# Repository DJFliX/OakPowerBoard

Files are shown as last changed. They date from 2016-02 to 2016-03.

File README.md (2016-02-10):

# OakPowerBoard
A Power Consumption board using the TCRT5000 to count pulses. The board is intended as a shield for DigiStump's Oak board. Check it out [here](http://digistump.com/oak/)!

##How does it look?
Great question, I've made screenshots of the board I sent to OSH-Park:
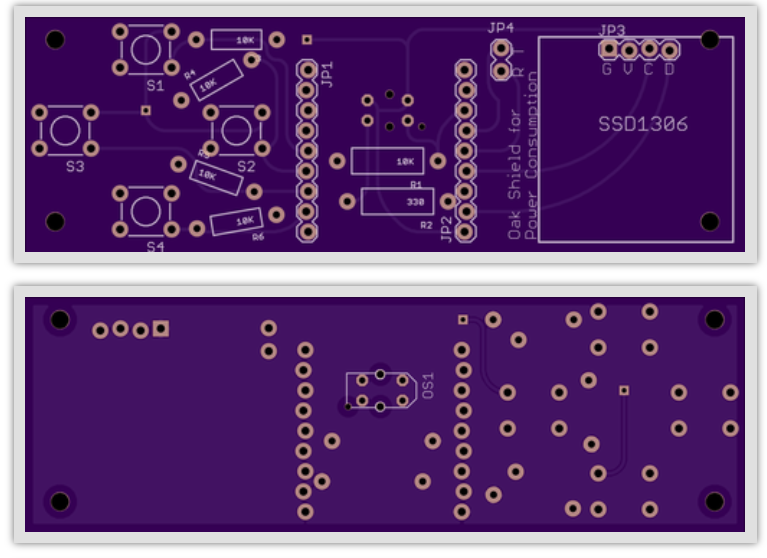
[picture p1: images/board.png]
Image of board


##Is the code finished?
I've made some progress on the code, but unfortunately to test the real sensor I'll have to wait until the board from oshpark arrive. For now, I'm simulating the pulse meter with a button. Below you can find a list of features that are already implemented as well as features that will be implemented in the near future.

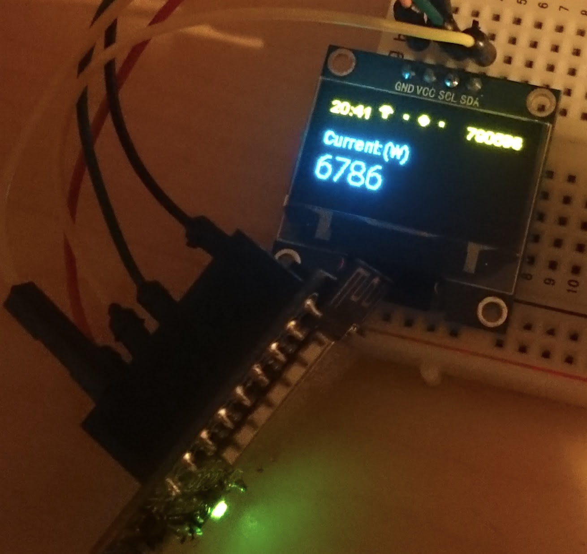
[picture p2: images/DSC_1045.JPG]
Image of firmware running on the Oak


Done:
- [X] Show (& calc) total consumption
- [X] Use interrupts to get button input + pulses
- [X] Use button input to switch between frames
- [X] Persistent storage of KWh counter

Future wishes:
- [ ] Add NTP time to sketch
- [ ] Implement timezone offset, apply to current time
- [ ] Keep track of total consumption for the day (and display this)
- [ ] Create some kind of menu for settings
- [ ] Set counter starting position
- [ ] Send consumption to some kind of server?
- [ ] Calibration of pulse detection?
- [ ] Multi-SSID
- [ ] Store measurements while there is no Wi-Fi connection
- [ ] Work stand-alone (without Wi-Fi connection) without switching to Config mode
- [ ] Reduce Flash memory wear by writing periodically instead of on every KWh increment

##Resources used
* [SparkFun Eagle Libraries](https://github.com/sparkfun/SparkFun-Eagle-Libraries) by [SparkFun](https://github.com/sparkfun)
* [TCRT5000 Eagle Library](https://github.com/mohamedpsx/Eagle-Libraries) by [mohamedpsx](https://github.com/mohamedpsx)

* [esp8266-oled-ssd1306](https://github.com/squix78/esp8266-oled-ssd1306) by [squix78](https://github.com/squix78))
* [EEPROMWriteAnything](http://playground.arduino.cc/Code/EEPROMWriteAnything) by the Arduino Community

* [AirSensor Energy Monitor tutorial](http://www.airsensor.co.uk/component/zoo/item/energy-monitor.html)
* [nongnu.org dtostrf](http://www.nongnu.org/avr-libc/user-manual/group__avr__stdlib.html#ga060c998e77fb5fc0d3168b3ce8771d42)
* [SSD1306 Tools Font Converter](http://oleddisplay.squix.ch)

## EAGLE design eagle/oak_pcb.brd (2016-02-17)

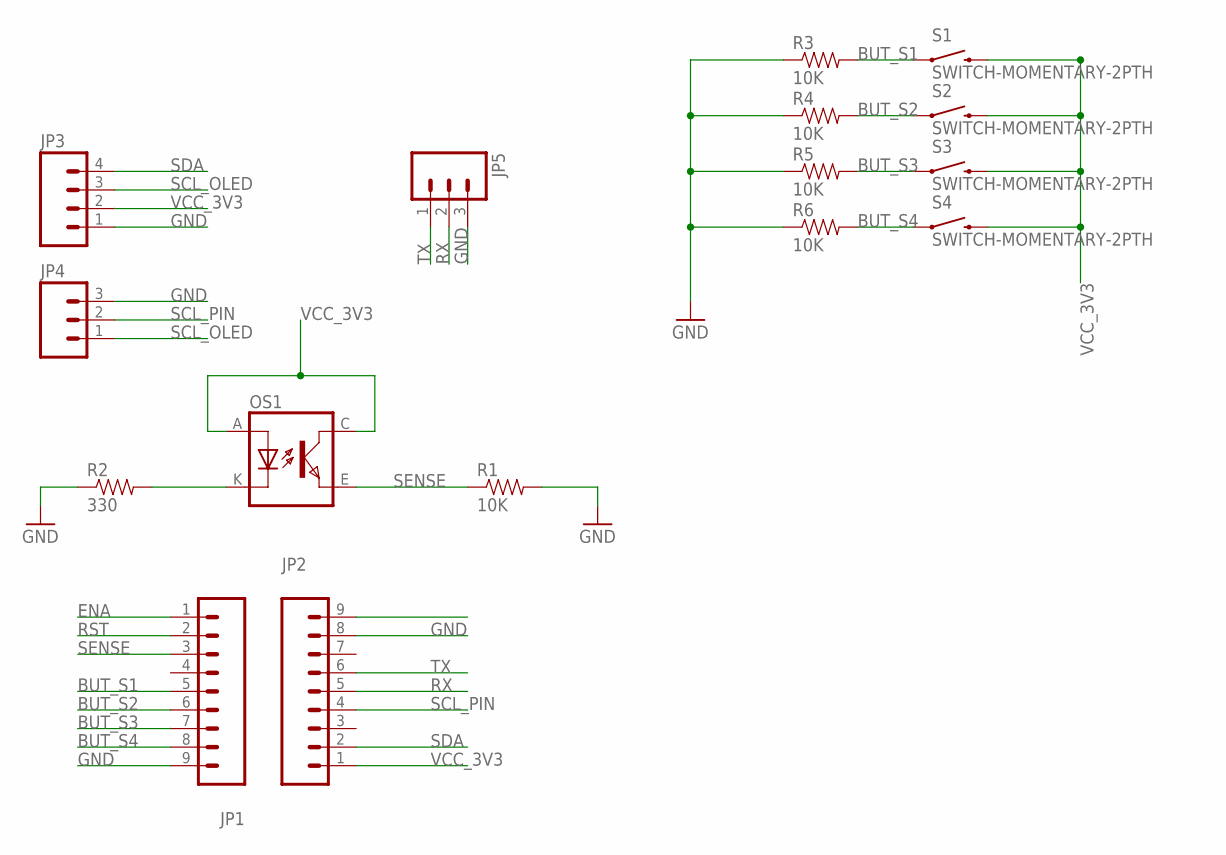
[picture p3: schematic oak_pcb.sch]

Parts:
JP1, JP2: M09LOCK; 1X09_LOCK
JP3: M04LOCK; 1X04_LOCK
JP4, JP5: M03LOCK; 1X03_LOCK
OS1: TCRT5000
R1, R3, R4, R5, R6: 10K; AXIAL-0.4
R2: 330; AXIAL-0.4
S1, S2, S3, S4: SWITCH-MOMENTARY-2PTH; TACTILE-PTH

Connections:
BUT_S1: JP1.5, R3.P$2 (2), S1.1
BUT_S2: JP1.6, R4.P$2 (2), S2.1
BUT_S3: JP1.7, R5.P$2 (2), S3.1
BUT_S4: JP1.8, R6.P$2 (2), S4.1
ENA: JP1.1
GND: JP1.9, JP2.8, JP3.1, JP4.3, JP5.3, R1.P$2 (2), R2.P$1 (1), R3.P$1 (1), R4.P$1 (1), R5.P$1 (1), R6.P$1 (1)
unnamed: OS1.K (CATHODE), R2.P$2 (2)
RST: JP1.2
RX: JP2.5, JP5.2
SCL_OLED: JP3.3, JP4.1
SCL_PIN: JP2.4, JP4.2
SDA: JP2.2, JP3.4
SENSE: JP1.3, OS1.E (EMITTER), R1.P$1 (1)
TX: JP2.6, JP5.1
VCC_3V3: JP2.1, JP3.2, OS1.A (ANODE), OS1.C (COLLECTOR), S1.3 (2), S2.3 (2), S3.3 (2), S4.3 (2)

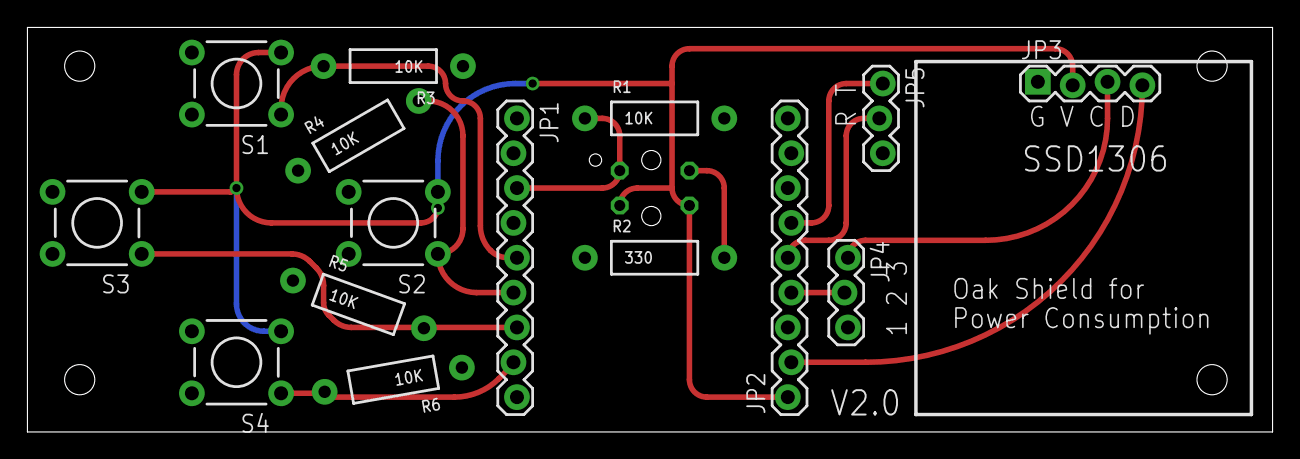
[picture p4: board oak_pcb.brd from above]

Board: 2 copper layers, 90.8 x 29.5 mm, 16 parts (1 on the bottom side), 13 nets.

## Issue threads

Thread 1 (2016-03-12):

Arduino sketch doesn't handle PUT and POST with payload

DJFliX, 2016-03-12:
Find out how to parse payload on incoming requests. Specifically, I'd like to parse the KWH value so we can set in from the browser sketch

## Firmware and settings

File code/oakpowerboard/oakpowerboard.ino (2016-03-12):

#include <Wire.h>
#include <EEPROM.h>

//https://github.com/squix78/esp8266-oled-ssd1306
#include "SSD1306.h"
#include "SSD1306Ui.h"

//Resources included with the sketch
#include "roboto_10.h"
#include "roboto_12.h"
#include "roboto_thin_20.h"
#include "images.h"

#include "eepromanything.h"

#define PULSES_PER_KWH 375
#define WH_PER_PULSE (1000.0F / PULSES_PER_KWH)

#define BTN_1 9
#define BTN_2 8
#define BTN_3 7
#define BTN_4 6
#define PULSE_PIN A0
#define DEBUG_LED 1

//#define DEBUG

#define EEPROM_READ_ADDR 0

struct config_t
{
  int state;
  double consumption_total;
  int pulse_count_current_kwh;
} storage;

double particle_total_kwh = 0;
char consumption_total_str[10] = "00000.00";

double particle_consumption_current = 0;
char consumption_current_str[6] = "Wait";

long time_since_last_pulse = millis();

// Initialize the oled display for address 0x3c
SSD1306   display(0x3c, 0, 2);
SSD1306Ui ui     ( &display );

struct measurement_values {
  int counter = 0;
  int value = 0;
  int hi = 0;
  int lo = 1024;
} analogVal;

struct measurement_strings {
  char current[5] = "0000";
  char hi[5] = "0000";
  char lo[5] = "0000";
} valStrings;

enum app_state {
  HOME,
  CALIBRATE
};

app_state current_state = HOME;

/* Drawing Resources */
bool draw_totalcount_frame(SSD1306 *display, SSD1306UiState* state, int x, int y);
bool draw_currentconsumption_frame(SSD1306 *display, SSD1306UiState* state, int x, int y);
bool draw_menu_frame(SSD1306 *display, SSD1306UiState* state, int x, int y);
bool msOverlay(SSD1306 *display, SSD1306UiState* state);

float get_consumption_from_time_since_last_pulse(long timeSinceLastPulse);

// this array keeps function pointers to all frames
// frames are the single views that slide from right to left
bool (*frames[])(SSD1306 *display, SSD1306UiState* state, int x, int y) = { 
  draw_totalcount_frame, 
  draw_currentconsumption_frame
};

// this array keeps function pointers to all frames
// frames are the single views that slide from right to left
bool (*others[])(SSD1306 *display, SSD1306UiState* state, int x, int y) = { 
  draw_menu_frame,
  draw_calibration_frame
};

bool (*overlays[])(SSD1306 *display, SSD1306UiState* state) = { 
  msOverlay 
};

bool isConnected = false;
bool b1_pressed = false;
bool b2_pressed = false;
bool b3_pressed = false;
bool b4_pressed = false;
bool pulse_triggered = false;

void toggle_b1() { b1_pressed = true; }
void toggle_b2() { b2_pressed = true; }
void toggle_b3() { b3_pressed = true; }
void toggle_b4() { b4_pressed = true; }
void trigger_pulse() { pulse_triggered = true; }

void setup() {
  Particle.variable("total", particle_total_kwh);
  Particle.variable("current", particle_consumption_current);
  EEPROM_readAnything(EEPROM_READ_ADDR, storage);
  if(storage.state != 0xFA) {
    storage.state = 0xFA;
    storage.consumption_total = 56713.0f;
    storage.pulse_count_current_kwh = 370;
    EEPROM_writeAnything(EEPROM_READ_ADDR, storage);
  }
  
  dtostrf(storage.consumption_total, 6, 2, consumption_total_str);
  
  ui.setTargetFPS(30);
  ui.setActiveSymbole(activeSymbole);
  ui.setInactiveSymbole(inactiveSymbole);
  ui.setIndicatorPosition(TOP);
  ui.setIndicatorDirection(LEFT_RIGHT);
  ui.setFrameAnimation(SLIDE_LEFT);
  ui.setTimePerFrame(7000);
  ui.setFrames(frames, 2);
  ui.setOverlays(overlays, 1);
  ui.init();

  display.flipScreenVertically();
  
#ifdef DEBUG
  pinMode(DEBUG_LED, OUTPUT);//Debugging LED
#endif
  attachInterrupt(digitalPinToInterrupt(BTN_1), toggle_b1, FALLING);
  attachInterrupt(digitalPinToInterrupt(BTN_2), toggle_b2, FALLING);
  attachInterrupt(digitalPinToInterrupt(BTN_3), toggle_b3, FALLING);
  attachInterrupt(digitalPinToInterrupt(BTN_4), toggle_b4, FALLING);
}

void loop() {
  int remainingTimeBudget = ui.update();
  long deadline = millis() + remainingTimeBudget;
  
  if (remainingTimeBudget > 0) {
    yield();
    if(b1_pressed == true) {
      switch(current_state) {
        case HOME:
          ui.setFrames(others, 2);
          ui.disableAutoTransition();
          current_state = CALIBRATE;
          break;
        case CALIBRATE:
          ui.setFrames(frames, 2);
          ui.enableAutoTransition();
          current_state = HOME;
          break;
      }
      //handle b1
      b1_pressed = false;
      yield();
    }
    
    if(b2_pressed == true) {
      //handle b2
      ui.nextFrame();
      b2_pressed = false;
      yield();
    }
    
    if(b3_pressed == true) {
      //handle b3
      ui.previousFrame();
      b3_pressed = false;
      yield();
    }
    
    if(b4_pressed == true) {
      //handle b4
      switch(current_state) {
        case CALIBRATE:
          analogVal.hi = 0;
          dtostrf(analogVal.hi, 4, 0, valStrings.hi);
          analogVal.lo = 1024;
          dtostrf(analogVal.lo, 4, 0, valStrings.lo);
          break;
      }
      b4_pressed = false;
      yield();
    }

    analogVal.counter++;
    if(analogVal.counter == 5) {
      analogVal.value = analogRead(PULSE_PIN);
      if(analogVal.value > analogVal.hi) {
        analogVal.hi = analogVal.value;
        dtostrf(analogVal.hi, 4, 0, valStrings.hi);
      }
      if(analogVal.value < analogVal.lo) {
        analogVal.lo = analogVal.value;
        dtostrf(analogVal.lo, 4, 0, valStrings.lo);
      }
      dtostrf(analogVal.value, 4, 0, valStrings.current);
      analogVal.counter = 0;
    }
    
    /*if(pulse_triggered == true) {
        storage.pulse_count_current_kwh++;
        if(storage.pulse_count_current_kwh == PULSES_PER_KWH) {
          storage.consumption_total++;
          storage.pulse_count_current_kwh = 0;
          EEPROM_writeAnything(EEPROM_READ_ADDR, storage);
        }
        yield();
        particle_consumption_current = get_consumption_from_time_since_last_pulse(time_since_last_pulse);
        particle_total_kwh = storage.consumption_total + ((((float)storage.pulse_count_current_kwh) * WH_PER_PULSE) / 1000.0F);
        dtostrf(particle_total_kwh, 6, 2, consumption_total_str);
        dtostrf(particle_consumption_current, 4, 0, consumption_current_str);
        time_since_last_pulse = millis();
        pulse_triggered = false;
        yield();
    }*/
#ifdef DEBUG
    digitalWrite(DEBUG_LED, millis() < deadline ? HIGH : LOW);
#endif
    yield();
    if(millis() < deadline) delay(deadline - millis());
  }
}

bool draw_totalcount_frame(SSD1306 *display, SSD1306UiState* state, int x, int y) {
  display->setTextAlignment(TEXT_ALIGN_LEFT);
  display->setFont(Roboto_Plain_10);
  display->drawString(0 + x, 20, "Total (kWh):");
  display->setFont(Roboto_Thin_Plain_20);
  display->drawString(0 + x, 32, consumption_total_str);
  return false;
}

bool draw_currentconsumption_frame(SSD1306 *display, SSD1306UiState* state, int x, int y) {
  display->setTextAlignment(TEXT_ALIGN_LEFT);
  display->setFont(Roboto_Plain_10);
  display->drawString(0 + x, 20, "Current: (W)");
  display->setFont(Roboto_Thin_Plain_20);
  display->drawString(0 + x, 34, consumption_current_str);
  return false;
}

bool draw_menu_frame(SSD1306 *display, SSD1306UiState* state, int x, int y) {
  display->setTextAlignment(TEXT_ALIGN_LEFT);
  display->setFont(Roboto_Plain_10);
  display->drawString(0 + x, 20, "MENU: (W)");
  return false;
}

bool draw_calibration_frame(SSD1306 *display, SSD1306UiState* state, int x, int y) {
  display->setTextAlignment(TEXT_ALIGN_LEFT);
  display->setFont(Roboto_Plain_10);
  display->drawString(12 + x, 16, "Current: ");
  display->drawString(12 + x, 28, "High: ");
  display->drawString(12 + x, 40, "Low: ");
  display->drawString(x, 52, "S4: RST S3: BCK S2: Ok");
  display->setTextAlignment(TEXT_ALIGN_RIGHT);
  display->drawString(128 + x, 16, valStrings.current);
  display->drawString(128 + x, 28, valStrings.hi);
  display->drawString(128 + x, 40, valStrings.lo);
  display->drawString(128 + x, 52, analogVal.value > ((analogVal.hi + analogVal.lo) / 2) ? "X" : " ");
  return false;
}

bool msOverlay(SSD1306 *display, SSD1306UiState* state) {
  //display->drawXbm(32, 0, 8, 8, wifiActive);
  display->setTextAlignment(TEXT_ALIGN_LEFT);
  display->setFont(Roboto_Plain_10);
  display->drawString(0, 0, valStrings.current); //This should be the current time
  //display->setTextAlignment(TEXT_ALIGN_RIGHT);
  //display->drawString(128, 0, String(millis()));
  return true;
}

float get_consumption_from_time_since_last_pulse(long timeSinceLastPulse) {
  long time = millis();
  long dsecs = (time - timeSinceLastPulse) / 100;
  if(dsecs < 4) { //4 dsecs = 0.4 sec: the highest supported interval for this sketch.
    time_since_last_pulse = time;
    return 0.0F;
  }
  float result = (WH_PER_PULSE / (dsecs / 36000.0F));
  return result;
}

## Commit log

2016-02-03 Added Board Files
    [oak_pcb.brd, oak_pcb.sch]
2016-02-03 Update readme and add board image from oshpark.
2016-02-04 Moved eagle files and modified Readme.md
    [oak_pcb.brd, oak_pcb.sch]
2016-02-04 Add the display loop
    Added three frames that are displayed. The current frames are: total
    power consumption (KWh), current consumption (W), and consumption today
    (KWh). Of course, data is static.
2016-02-04 Added initial pulse calculation and string conversion
    When a pulse is detected (currently emulated using a button) the
    current power consumption is calculated and displayed on the screen.
    The value for “Current (W)” is now actually based on the float value.
    Total is based on the float value, but is not updated properly. Today
    is not implemented yet, as we don’t have time yet.
2016-02-07 Corrected current consumption calculation formula.
    [oakpowerboard.ino]
2016-02-07 Fixed calculation of total KWH
    [oakpowerboard.ino]
2016-02-07 Delay with the remaining budget after measuring pulse instead
    Also: comment these lines out because apparently a delay is a problem.
    [oakpowerboard.ino]
2016-02-09 Removed the frame that we don't use (consumption today)
2016-02-09 Oops... forgot to commit the changes concerning the not-so-dynamic number of frames and overlays...
2016-02-09 Replace the digitalRead with interrupt-based triggers.
    [oakpowerboard.ino]
2016-02-09 Increase the display time per frame
2016-02-16 Move fonts to root, apparently Arduino 1.6.5 does not like subfolders.
    Strangely enough, it worked on 1.6.7… But that version had other issues.
    [oakpowerboard.ino]
2016-02-16 Added extra yields to lower the WiFi congestion during the loop
    Also fixed an ugly bug that made the loop delay forever.
    [oakpowerboard.ino]
2016-02-17 Board update, fixed some unfortunate mistakes on my part.
    The oak only has a single Analog pin, I attached the sensor to one of
    the digital pins. I can bodge the existing boards, but I’ve chosen to
    order new boards anyway. So this will be version 2.0, also containing a
    Ground pin for the UART connection as well as bigger holes for the IR
    sensor and a jumper to set the module in ‘bootloader’ mode.
    [oak_pcb.brd, oak_pcb.sch]
2016-02-17 Update pin definition because of design bodge.
    [oakpowerboard.ino]
2016-02-17 Added a Menu Frame (for further development).
2016-02-17 Remove interrupt (because we can't use that anymore :( )
2016-02-17 Fix typo that made the code run incorrectly.
    [oakpowerboard.ino]
2016-02-17 Added a Calibration frame that displays the current analogRead value
    Also displays some static values for high and low. As a tease.
2016-02-24 Put the character arrays in a struct to structure the code a little more.
    Also added a High/Low/Current display in the “calibration menu” thingie.
2016-03-12 Fix crashes if the deadline >= millis()
    [oakpowerboard.ino]
2016-03-12 Change debug pin to on-board LED

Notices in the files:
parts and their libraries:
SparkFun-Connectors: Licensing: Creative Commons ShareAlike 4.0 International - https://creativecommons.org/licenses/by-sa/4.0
